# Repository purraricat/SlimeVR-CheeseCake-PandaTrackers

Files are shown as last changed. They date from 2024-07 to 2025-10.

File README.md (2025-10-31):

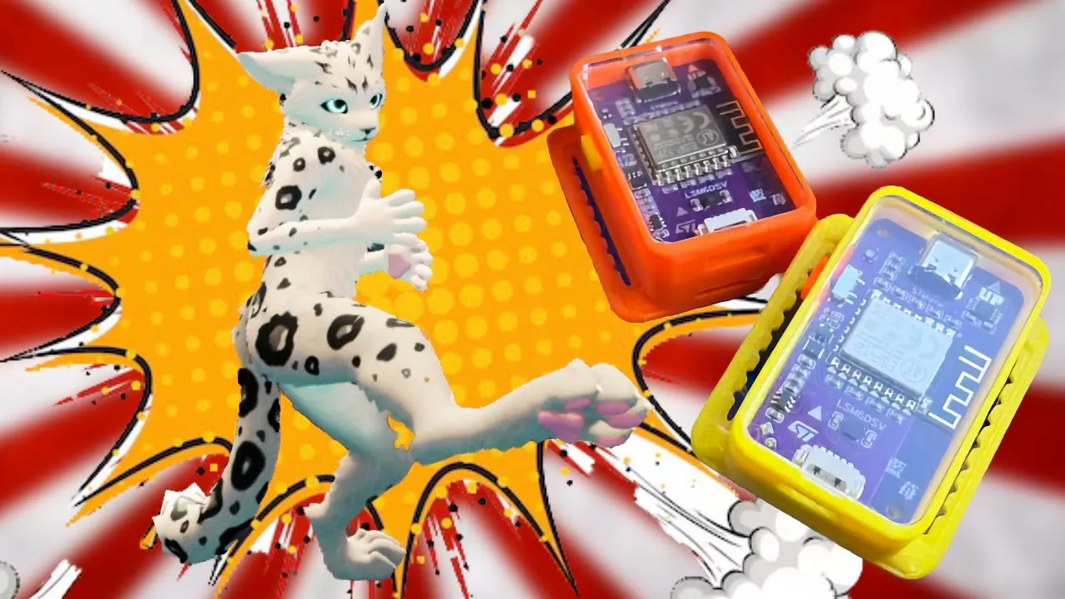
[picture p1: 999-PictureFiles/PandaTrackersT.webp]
Intro-GIF (https://discord.gg/ZzgH7QkN7F)
 

# SlimeVR IMU Comparison
[A comparison of IMUs](docs/imu-comparison.md) currently popular for SlimeVR trackers.

# LSM IMU Calibration Guide
LSM6DSV IMU 6 sides [calibration guide](docs/imu-calibration.md)  

# LSM6DSV Best Practices
[LSM6DSV tips](docs/LSM6DSV-tips.md) for achieving the best performance and consistent +45 min reset times with LSM6DSV IMU based SlimeVR trackers.
 
# Panda Trackers 3D Case Designs

**Update 2025:** this is outdated now.   
Old info / designs are valid **only for old** 2024 and earlier Panda Trackers based on the Cheesecake design.     
See [Panda Trackers discord](https://discord.pandapro.nl) to buy the latest trackers.

Panda Trackers are based on upgraded 3D case design of Cheesecake trackers. These cases are very durable and feature integrated 40mm clips for straps. Panda cases are optimised for dancing and active use.

### Features 
* Simplified case design
* Extremely durable 
* Fixed center of mass (no more wobbly trackers)
* Cute cover graphics  
* Added latches for covers
* Fits self tapping M2 screws
* Uses a simple split 4x USB-C cable instead of a charging dock 

### Printing
Designed for PETG filament only. 
Settings 3 walls and 15% cubic infill.

### Panda Trackers more info
* Visit Panda Trackers Discord for more info https://discord.gg/ZzgH7QkN7F 
* Panda Trackers Youtube https://youtube.com/@pandatrackers

### Panda Trackers License
Creative Commons Attribution-Noncommercial-Share Alike

Panda Trackers License


### SlimeVR-CheeseCake
Very delicious [Cheesecake](https://github.com/Sorakage033/SlimeVR-CheeseCake). Designed by Sorakage

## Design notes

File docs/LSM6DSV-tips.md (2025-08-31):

# LSM6DSV Best Practices

**2025 Update:** Panda Trackers use new firmware in 2025. It does not have 6 sides calibration anymore. Current reset times are 90 min. The guide bellow is only for trackers that still use old **sfusion** firmware. 

This guide discusses how to achieve great performance (consistent +45 min resets) using trackers with LSM6DSV IMU. You can skip hardware and firmware parts, if you are using Panda Trackers (LSM6DSV).  

 ## Six sides calibration

Make sure you have done the LSM6DSV IMU [6 sides calibration](imu-calibration.md) correctly.  

 ## Using LSM6DSV trackers

To start your VR session, always place trackers on a stable surface (table or floor) and turn them on. Wait a few seconds for sensors to initialize. A common mistake is putting trackers on your body and turning them on, which will increase drift a lot.

You need to warm your trackers each time your start them. There are many ways to do it but the simplest one is to turn them on and play for 20 min. Trackers will reach stable working temperature after that. You need to take trackers off and place on the stable surface like floor and leave to sit for a few seconds, so sensor could recalibrate at a working temperature. You can put your trackers back on and continue playing, enjoying +45 min resets for the rest of the session! 

Visit Panda Trackers Discord for more info and help https://discord.gg/ZzgH7QkN7F

Return Panda Trackers [main README.md](../README.md) 

 ## Extra info for DIY LSM6DSV (non Panda trackers) 

 ## LSM6DSV hardware

Make sure you are using a correct chip. There are many LSM6 family IMUs (example LSM6DSO, LSM6DSR) but only the **LSM6DSV** is the top model with the best performance. 

You need well designed trackers that follow LSM6DSV design specifications (many SlimeVR designs do not follow this). Recommended well tested designs: Cheesecake and Panda. Get [Panda Trackers](https://discord.gg/ZzgH7QkN7F). 

There are a few reports of bad performance of LSM6DSV trackers from some SlimeVR market sellers but not enough data to comfirm if it's hardware design flaws or just wrong firmware and settings. It's possible to damage your IMU building DIY trackers too. 

 ## Correct firmware 

 Make sure you are using correct FW: [l0ud/sfusion](https://github.com/l0ud/SlimeVR-Tracker-ESP-BMI270/tree/sfusion) (a backup Panda Trackers [LSM sfusion](https://github.com/purraricat/Panda-Trackers-LSM-sfusion/tree/sfusion)). This FW is well tested on LSM6DSV and provides GREAT and CONSISTENT results, it has been merged to the main SlimeVR/main now. Do not use the SlimeVR/main though, it will still provide worse reset times over original sfusion. Make sure you are flashing the correct l0ud/sfusion brach and not just the default l0ud/main too. You can use [web flasher](https://slimevr-firmware.unlogisch.ch) for easy flashing. 
 
 There are many versions of sfusion, do not mistake them. Some may sound better and have extra features added like sfusion-tcal or dynamic-sfusion but all have delivered worse reset times over the original l0ud/sfusion then tested. 
 
 Do not use any of MBE firmwares, those are expirimental and have many bugs. MBE requires extra calibration steps before every session. MBE fw's are not optimized and will cause issues on the esp-12f used in Pandas and Cheesecakes. MBE has issues with extensions too.

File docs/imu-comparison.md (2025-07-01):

# SlimeVR IMU Comparison
A comparison of currently popular IMUs for SlimeVR trackers.  

## Index
- [LSM6DSV](#lsm6dsv)
- [LSM6DSO](#lsm6dso)
- [ICM-45686](#ICM-45686)
- [BMI270](#bmi270)
- [BMI160](#bmi160)
- [BNO085](#bno085)
- [MPU9250](#mpu9250)
- [MPU6500](#mpu6500)
- [MPU6050](#mpu6050)
- [Addendum](#addendum)

## Criteria
We rank these chips in the following categories: Reset Time, Cost, Availability and Build quality.

## General Recommendations
LSM6DSV is the best IMU in terms of performance since the 2024. LSM6DSV offers consistent +45min resets. Much higher and most importantly consistent reset times over all budget BMI270, LSM6DSO, ICM-45686 IMU options. Neither LSM or BMI requires a stable magnetic environment. 

BNO085 IMUs main feature is sensor fusion with integrated magnetometer. This IMU requires a stable magnetic enviroment to perform well. Majority of homes do not have good magnetic enviroment. For this reason, SlimeVR trackers using BNO085 IMUs are sold with the featured turned off and do perform rather poor on a level with budget IMUs like the BMI270, Making the BNO085 a bad price to performance choice.

When referring to the order of the IMUs on this page, bear in mind that they're listed roughly in order of best to worst.

---
## LSM6DSV
The LSM6DSV is a newest IMU for DIY SlimeVR in 2024.  
IMU offers very good reset times, works in bad magnetic enviroments, the best option for VR dancing and fitness use.    

|Reset time |Cost |Availability|Build quality|
|:---:|:---:|:---:|:---:|
|45-90 min |~$7 |Good|Excellent |

> Currently there are two popular firmwares for LSM6DSV offering 40-90 min resets. Sfusion needs one time calibration and offers good reset times from the start. Dynamic sfusion does not require a calibration but takes over an hour to reach a comparable performance with well calibrated sfusion each time starting a new session.  
 
|Pros |Cons |
|---|---|
|Accurate |Requires Quality Tracker design |
|Reliable |Requires warmup before use |
|Consistent Reset times | |
|Perfect for dancing| |

LSM6DSV IMU chips and SlimeVR trackers using this IMU can be bought at [Panda Trackers](https://discord.gg/VPjtkujaVs).

LSM6DSV sfusion firmware is stable and has been merged to the main SlimeVR branch. Very good LSM6DSV performance using sfusion has been confirmed by over hundreds of users now. 

**Important:** LSM6DSV is new and more accurate IMU sensor, it will not fix all SlimeVR DIY tracker problems, it will not improve reset times for DIY trackers. To get +40 min reset times you need: quality PCB design, quality tracker design, correct firmware and good calibration.  

---
## LSM6DSO
It's a budget IMU option with a possible performance slightly above the BMI270 but way below the LSM6DSV. Little data on this IMU.

---
## ICM-45686
Budget IMU option. Moving fast (dancing, fitness) will make trackers drift much faster with this IMU, similar to the BMI270. Has a magnetometer built in. Most homes do not have a good magnetic environment though. SlimeVR trackers are shipped with the magnetometer featured turned off.

|Reset time |Cost  |Availability|Build quality|
|:---:|:----:|:---:|:---:|
|10 - 30min |~$5 |Sufficient  |Great |

---
## BMI270
The BMI270 is slightly newer and better performing version of the BMI160 while still being affordable.

|Reset time |Cost  |Availability|Build quality|
|:---:|:----:|:---:|:---:|
|10 - 30min |~$3.8 |Sufficient  |Great |

|Pros |Cons |
|---|---|
|Cheap | [Requires manual calibration the first time](#imu-calibration) |
|Reliable | Only available in module form from a single source |
|Smooth | Experimental, still in testing |
|Single time calibration| Performance data not taken from survey |

---
## BMI160
The BMI160 is the current go-to IMU for DIY SlimeVR.
It is an easily available chip with decent performance and good reliability.

|Reset time |Cost  |Availability|Build quality|
|:---:|:----:|:---:|:---:|
|10 - 20min |~$1.50|Sufficient  |Good |

|Pros |Cons |
|---|---|
|Cheap | [Requires manual calibration the first time](#imu-calibration) |
|Reliable | |
|Smooth | |
|Single time calibration| |

---
## BNO085

This is the official IMU used in Crowd Supply SlimeVR trackers. Performance varies a lot using the BNO085 IMU. It's outdated model in 2025 too. NOT recommended for DANCING or any active use.

Two major factors affect BNO085 drift times: magnetic environment and type of use. Most homes do not have a good magnetic environment, so SlimeVR trackers are shipped with this feature turned off. This automatically caps tracker performance below 20 min, in best case scenario.  

Second issue, BNO085 sensor does not like fast movement, which makes it poor choice for dancing and combat games. Moving fast makes BNO085 trackers drift much faster. Jumping, stomping feet might make them fail completely (also know as feet snapping). BNO085 is not recommended for dancing. It hardly can last a single fast song without drifting and even slow songs will require a reset every 2-3 songs. For this reason BMI270 and LSM6DSV chips are recommended for dancing, fighting type of games.

|Reset time |Cost |Availability|Build quality|
|:---:|:---:|:---:|:---:|
|3 - 45 min|~$13 |Sufficient  |Excellent |

|Pros |Cons |
|---|---|
| |Expensive |
|Magnetometer |Magnetometer unusable by 99% users |
| |High drift rate with magnetometer turned off |
| |Fails to track fast movements |
| |Bad price to performance ratio |
| |Requires warmup before use |

> Please note, there is a lot of misinformation being spread about the BNO085 by the SlimeVR CrowdSupply project. SlimeVR documentation ranks BNO085 as the best chip. It lists only the best case scenario reset times for the BNO085 in a perfect magnetic enviroment and staying still through all of that time. Does not mention anything about issues in dancing and fighting games.

---
## MPU9250

<b>Not recommended for new designs.</b>

The MPU9250 (currently ran in several modes) is a newer installment of the MPU lineup.

|Reset time |Cost |Availability|Build quality|
|:---:|:---:|:---:|:---:|
|10 - 40 min|~$7  |Insufficient|Mediocre |

|Pros |Cons |
|---|---|
|Affordable |Very prone to counterfeit/DOA units |
|Smooth |Sensitive to bad magnetic environments |
|Reliable |[Requires manual calibration the first time](#imu-calibration) |

`Comment: Finding legitimate MPU9250s has become exceedingly difficult due to counterfeits and DOA IMUs. Buy at your own risk.`

---
## MPU6500

<b>Not recommended for new designs.</b>

The MPU6500 is the middle ground of the MPU chips available.
The drift time of this IMU may be a slight improvement over the MPU6050.

|Reset time |Cost |Availability|Build quality|
|:---:|:---:|:---:|:---:|
|5 - 10 min |~$1  |Sufficient  |Mediocre |

|Pros |Cons |
|---|---|
|Affordable |High drift rate |
|Available |More expensive than the 6050 counterpart |
|Smooth |Failure rate inconsistent |
| |[Calibration on each start](#imu-calibration)|

`Comment: Tracking slightly better than the MPU6050.`

---
## MPU6050

<b>Not recommended for new designs.</b>

The MPU6050 will get you started with SlimeVR for cheap.

|Reset time |Cost  |Availability|Build quality|
|:---:|:----:|:---:|:---:|
|1 - 5 min  |~$1.04|Sufficient  |Poor |

|Pros |Cons |
|---|---|
|Cheap |High drift rate |
|High availability|High failure rate |
| |[Calibration on each start](#imu-calibration)|

`Comment: Order more than you need because of the higher failure rate, it is not uncommon to find 2 to 3 bad chips in a batch.`

---
# Addendum

## What's the difference between an IMU with a magnetometer (9 DOF) and an IMU without a magnetometer (6 DOF)?

IMUs with a magnetometer work like a compass and use the Earth's magnetic field as a reference point to eliminate gyroscope drift, however they require a stable magnetic environment or else they will perform erratically. IMUs without a magnetometer don't require a stable magnetic environment, but are prone to gyroscope drift over time due to being unable to differentiate sensor noise from actual movement, and so will slowly spin in the yaw axis over time. 

## How can I check if I have an acceptable magnetic environment?

You can check by downloading any magnetometer app that shows what your magnetic field strength is in uT and by walking around your playspace. You may want to check at varying heights, such as at chest level, waist level, and ankle level. An option available on both iOS and Android is the app, Physics Toolbox Magnetometer. If you do use Physics Toolbox Magnetometer, you only need to pay attention to the **total**, not the X, Y, or Z components. Most phones have a magnetometer, but if yours does not, then there is no way to be exactly sure of your magnetic environment, but you can make some educated assumptions.

## My app shows around X uT, is that okay?

There's no one value that's acceptable. What matters is that the range of values is low. There is currently limited data to give an exact range, but a good baseline seems to be a range of less than or equal to 5 uT. For example, 20-25 uT would be okay as would 40-45 uT, but a range from 20-40 uT would likely be too unstable to use.

## What determines a "poor magnetic environment"?

Often things made of steel or other ferromagnetic materials contribute most to a poor magnetic environment. Some common examples of things that might affect your magnetic environment include, but are not limited to: spring mattresses, radiators, PC cases, desktop speakers, or furniture that's made of steel. In most cases, the effect that these things will have extend about 6-12 inches (15-30 cm) and within that range may cause the IMU to rotate incorrectly. The size and amount of mass directly impacts the size of the effected area; a paper clip might only affect your IMU if it's directly next to it, whereas a steel bedframe might affect an area 6-12 inches (15-30 cm) away as previous mentioned. In most cases, depending on the size of your playspace, these issues of certain objects causing interference can be mitigated by avoiding or reposition them. Regardless, other factors such as the wiring or rebar in your building could also affect your magnetic environment. These last few examples are harder to predict and illustrate why it's important to test with an app before assuming you might have a stable magnetic environment.

It's also worth mentioning that some controllers have magnets in them, either to hold the battery door closed or for the trigger. As such, placing your controller near a tracker with a magnetometer may cause it to spin slightly.

## Does magnetic interference cause drift?

No, but you may still need to reset. When in an area of magnetic interference an IMU with a magnetometer will reorient itself the same way a compass will when put near a magnet; if you take the magnet away from the compass, the compass will return pointing towards magnetic North. As mentioned though, you may still find yourself needing to reset. For instance, if your bed has a steel bedframe you'll likely need to perform a reset so that your trackers are facing the correct orientation. If you then move somewhere else within your playspace you'll likely then need to reset once again.

## Can I still use my IMU with a magnetometer if I don't have a stable magnetic environment?

This cannot be recommended. When run without the magnetometer, IMUs with magnetometers such as the MPU9250 and ICM20948, perform much worse. That said, if for whatever reason you do want to use your IMU without the magnetometer, the MPU6500 or MPU6050 firmware can be used on the MPU9250 instead, and the ICM20948 can run in 6DOF mode.

## IMU Calibration

Some IMUs, such as the BMI270, BMI160, MPU9250, and MPU+QMC5883L, require manual calibration. This only needs to be performed once upon first setting up your SlimeVR tracker, however, you may need to perform the calibration multiple times before reaching satisfactory results. More information on how you would calibrate your IMUs can be [found here.](../server/imu-calibration.md)

---
### Credits
*Created by smeltie, edited by calliepepper and nwbx01*

A big thanks to everyone who took the time to fill out the survey.

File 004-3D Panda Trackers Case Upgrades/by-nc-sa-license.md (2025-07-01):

### Panda Trackers License
Creative Commons Attribution-Noncommercial-Share Alike

Panda Trackers License (https://creativecommons.org/licenses/by-nc-sa/4.0/)

* Attribution — You must give appropriate credit , provide a link to the license, and indicate if changes were made . You may do so in any reasonable manner, but not in any way that suggests the licensor endorses you or your use.
* NonCommercial — You may not use the material for commercial purposes .
* ShareAlike — If you remix, transform, or build upon the material, you must distribute your contributions under the same license as the original.
No additional restrictions — You may not apply legal terms or technological measures that legally restrict others from doing anything the license permits.  

### Panda Trackers more info
* Visit Panda Trackers Discord for more info https://discord.gg/ZzgH7QkN7F 
* Panda Trackers Youtube https://youtube.com/@pandatrackers

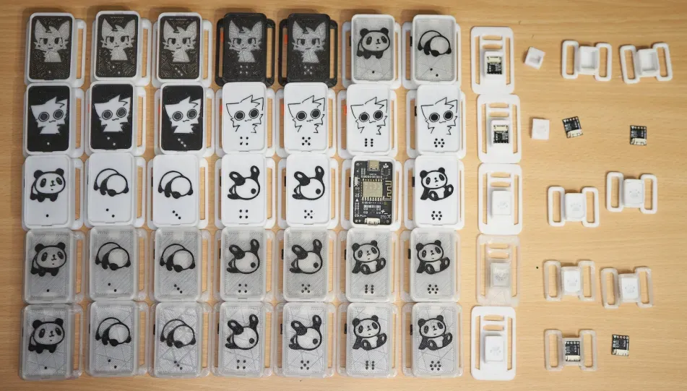
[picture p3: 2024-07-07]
999-PictureFiles/PandaDesigns.webp

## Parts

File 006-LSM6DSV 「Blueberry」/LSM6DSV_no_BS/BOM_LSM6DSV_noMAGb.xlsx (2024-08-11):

No. | Quantity | Comment | Designator | Footprint | Value | Manufacturer Part | Manufacturer | Supplier Part | Supplier
1 | 1 | 1uF | C1 | C0402 | 1uF | CL05A105KA5NQNC | SAMSUNG(三星) | C52923 | LCSC
2 | 4 | 100nF | C2,C3,C9,C10 | C0402 | 100nF | CL05B104KO5NNNC | SAMSUNG(三星) | C1525 | LCSC
3 | 2 | 10uF | C4,C5 | C0603 | 10uF | CL10A106KP8NNNC | SAMSUNG(三星) | C19702 | LCSC
4 | 1 | 10uF | CP1 | C0603 |  | CL10A106KP8NNNC | SAMSUNG(三星) | C19702 | LCSC
5 | 1 | 1N5819WS | D1 | SOD-323_L1.8-W1.3-LS2.5-RD |  | 1N5819WS | Hottech(合科泰) | C191023 | LCSC
6 | 1 | 2.4GHz | ESP1 | WIFIM-SMD_ESP-12F-ESP8266MOD | 2.4GHz | ESP-12F(ESP8266MOD) | Ai-Thinker(安信可) | C82891 | LCSC
7 | 1 | 22kΩ | FB1 | R0402 | 22kΩ | 0402WGF2202TCE | UNI-ROYAL(厚声) | C25768 | LCSC
8 | 2 | 100kΩ | FB2,VD2 | R0402 | 100kΩ | 0402WGF1003TCE | UNI-ROYAL(厚声) | C25741 | LCSC
9 | 1 | 2.2uH | L1 | IND-SMD_L2.5-W2.0_YXMBL252010P | 2.2uH | APH252010T2R2M | APV(爱普微) | C5349606 | LCSC
10 | 1 | NH-B2020RGBA-HF | LED1 | LED-ARRAY-SMD_4P-L2.1-W2.1-TL_NH-B2020RGBA |  | NH-B2020RGBA-HF | 国星光电 | C2874116 | LCSC
11 | 1 | TP4057-42-SOT26-R | P1 | SOT-23-6_L2.9-W1.6-P0.95-LS2.8-BL |  | TP4057-42-SOT26-R | TOPPOWER(南京拓微) | C12044 | LCSC
12 | 1 | AO3401A | Q1 | SOT-23_L2.9-W1.3-P1.90-LS2.4-BR |  | AO3401A | AOS | C15127 | LCSC
13 | 7 | 4.7kΩ | R1,R2,R3,R4,R5,R8,RD3 | R0402 | 4.7kΩ | 0402WGF4701TCE | UNI-ROYAL(厚声) | C25900 | LCSC
14 | 1 | 10kΩ | R9 | R0402 | 10kΩ | 0402WGF1002TCE | UNI-ROYAL(厚声) | C25744 | LCSC
15 | 1 | 2kΩ | RA1 | R0402 | 2kΩ | 0402WGF2001TCE | UNI-ROYAL(厚声) | C4109 | LCSC
16 | 2 | 5.1kΩ | RD1,RD2 | R0402 | 5.1kΩ | 0402WGF5101TCE | UNI-ROYAL(厚声) | C25905 | LCSC
17 | 1 | 1kΩ | RL1 | R0402 | 1kΩ | 0402WGF1001TCE | UNI-ROYAL(厚声) | C11702 | LCSC
18 | 1 | 180kΩ | RS1 | R0402 | 180kΩ | 0402WGF1803TCE | UNI-ROYAL(厚声) | C25760 | LCSC
19 | 1 | SSSS811101 | SW1 | SW-SMD_SSSS811101 |  | SSSS811101 | ALPSALPINE(阿尔卑斯阿尔派) | C109335 | LCSC
20 | 1 | M3406-ADJ | U1 | SOT-23-5_L3.0-W1.7-P0.95-LS2.8-BR |  | M3406-ADJ | 西安航天民芯 | C83224 | LCSC
21 | 1 | LSM6DSVTR | U5 | LGA-14_L3.0-W2.5-P0.50-TL |  | LSM6DSVTR | ST(意法半导体) | C5267399 | LCSC
22 | 1 | CH340X | UART1 | MSOP-10_L3.0-W3.0-P0.50-LS5.0-BL |  | CH340X | WCH(南京沁恒) | C3035748 | LCSC
23 | 1 | TYPE-C 16PIN 2MD(073) | USB1 | USB-C-SMD_TYPE-C-6PIN-2MD-073 |  | TYPE-C 16PIN 2MD(073) | SHOU HAN(首韩) | C2765186 | LCSC
24 | 1 | 220kΩ | VD1 | R0402 | 220kΩ | 0402WGF2203TCE | UNI-ROYAL(厚声) | C25767 | LCSC

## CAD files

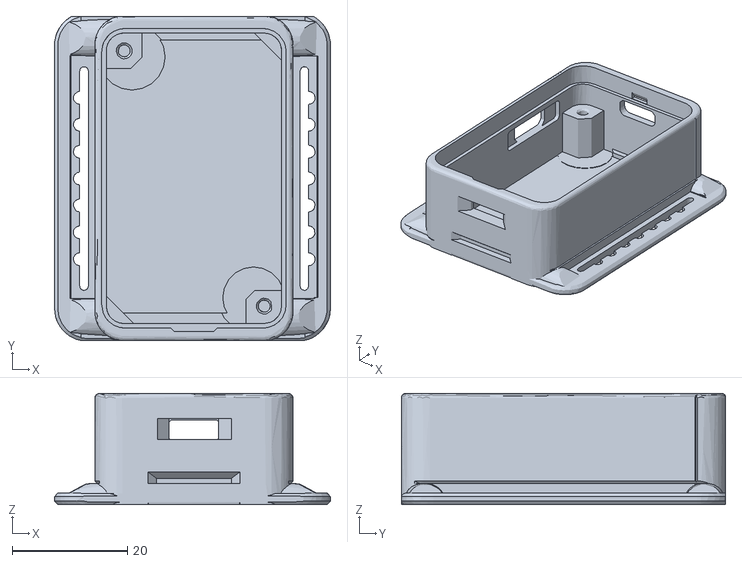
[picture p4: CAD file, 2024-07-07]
004-3D Panda Trackers Case Upgrades/PandaTrackers-Case-w40straps.stl
47.9 x 56.3 x 19.3

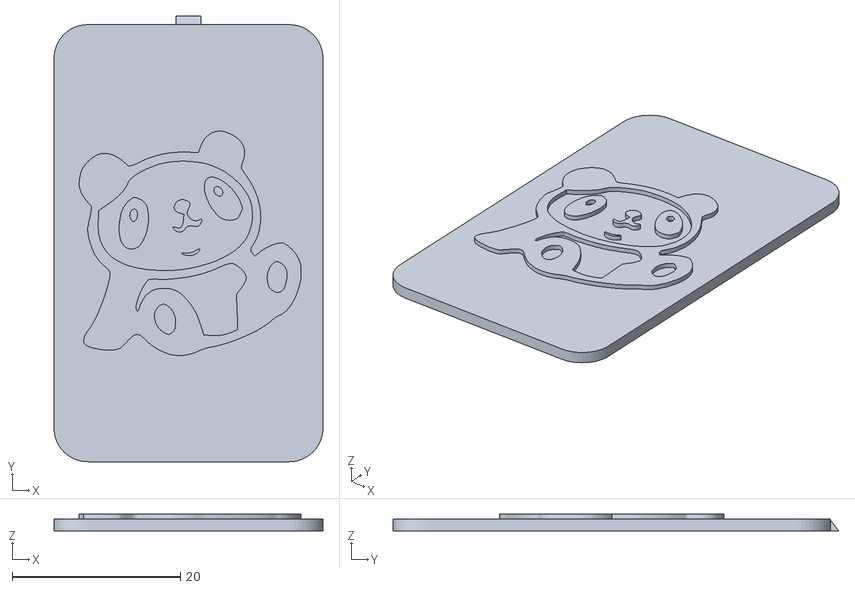
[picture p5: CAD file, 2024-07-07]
004-3D Panda Trackers Case Upgrades/Panda Case Lid.stl
32.0 x 53.0 x 2.00

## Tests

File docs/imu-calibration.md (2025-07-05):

## IMU Sensor calibration

This guide is specifically for the LSM6DSV IMU calibration running (l0ud/sfusion FW) but you can use same steps for BMI160, BMI270 and LSM6DSO models too. 
This guide will not work for trackers with kounocom/dynamic-sfusion FW (Panda Trackers after 2025 April), dynamic FW calibrates automatically standing still (blue light glows solid). 

6 sides calibration needs to be done only once after you get or build your new tracker set.

  - For best results, **calibrate when the trackers are warmed up** - turn them on and wear them for 20 minutes,
    wait for the temperature to stabilize at 30-40 degrees C, only then calibrate.

    Enable developer mode in SlimeVR settings to see tracker temperature.

### LSM6DSV - 6 sides calibration

  - **Step 0: Turn off the tracker. Flip it upsidedown and turn power on.**
    
    > The LED will be lit continuously. Wait for 2s and flip tracker back up while the LED is still solid. Wait, do not move the tracker.
    
  - **Step 1: Make sure tracker does not move, the LED will flash 3 times when gyroscope calibration begins.**
    
  - **Step 2: LED will flash 6 times when accelerometer calibration begins and it will flash 2 short blinks that the current side has been recorded.**

    > The accelerometer calibration process requires you to **hold the device in 6 unique orientations** (e.g. sides of a cube),
    > keep it still, and not hold or touch for 3 seconds each. It uses gravity as a reference and automatically detects when it is stabilized - this process is not time-sensitive.

    > If you are unable to keep it on a flat surface without touching, press the device against a wall, it does not have to be absolutely perfect.

    **There will be two very short blinks when each position is recorded.**
    
    Rotate the device 90 or 180 degrees in any direction. It should be on a different side each time. Continue to rotate until all 6 sides have been recorded. I like rotating tracker on one axis 90' degrees to record all 4 sides, then flip axis to record 2 sides left. This makes keeping track of recorded sides easy.

    Watch calibration video - https://www.youtube.com/watch?v=0kHLL7mCRfo
    
    The last position has a long flash when recorded, then LED will start blinking normaly and tracker will appear connected in the SlimeVR server. All calibration data has been saved on the tracker and you can turn it off safely now. 

If tracker has an extension, you need to repeat the same steps turning the tracker off, flipping the extension upsidedown and turning the tracker on, and follow the LED just like you did before to record all 6 sides of the extension.   

  #### Additional info  

   If you have any problems with this procedure, connect the device via USB and open the serial console to check for any warnings or errors that may indicate hardware problems.
  
If you have the tracker connected via USB and open the serial console, you will see text directions in addition to the LEDs. This can help to calibrate the tracker and understand the procedure. Use this only for learning the process.

Calibration will be bad with USB cable plugged because it will pull on the board and generate heat charging the tracker too. So to get a good calibration always redo it without the USB cable plugged and just follow the LED light.

  #### Common mistakes

  Trackers not entering calibration mode. Make sure to wait 2s after switching the tracker on and only then flip it up.

  Calibrating tracker without warming up. This is especially important for the LSM6DSV, if you will calibrate it at a room temperature 25'C but the tracker normal working temperature while you play is 38'C, the calibration will be bad, making tracker drift much faster.  

  Make sure you are using a stable, level surface. If you have wobly computer desk, user floor, stool or anything else more stable for the calibration.

  Moving your tracker during the calibration, if you will bump your table by accident, even walk close to the table/tracker, it might be enough for the tracker to record. Making calibration invalid. You will need to turn off tracker and start calibration again.  

Return Panda Trackers [main README.md](../README.md)

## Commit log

2024-08-02 Update imu-comparison.md added LSM6DSV
2024-08-02 Update imu-comparison.md fix LSM6DSV
2024-08-04 Update README.md
    imu comparison
2024-08-11 no mag lsm6dsvs
    [BOM_LSM6DSV_noMAGb.xlsx, PickAndPlace_LSM6DSV_noMAGb.xlsx]
2025-01-13 Updated imu-comparison.md
